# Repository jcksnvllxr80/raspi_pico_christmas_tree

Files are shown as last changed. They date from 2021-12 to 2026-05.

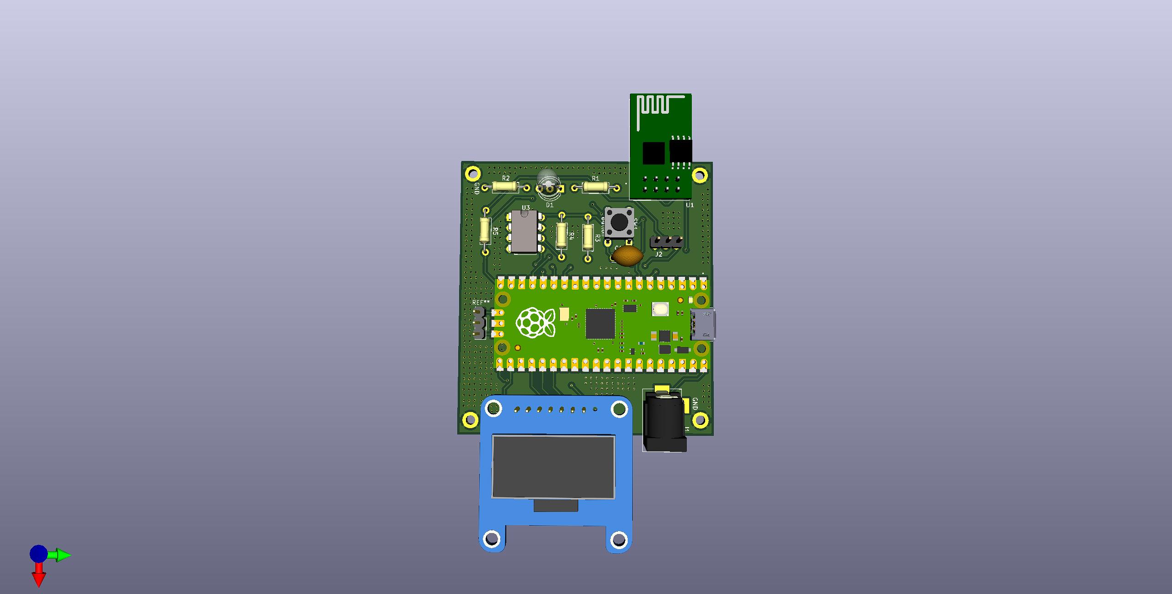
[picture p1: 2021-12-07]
pcb/images/raspi_pico_christmas_tree_front_3d.jpg

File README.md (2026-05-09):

# Raspberry Pi Pico with ws2812 LED string, SSD1306 OLED display, esp8266 (esp-01), and 24LC512 EEPROM. "Christmas Lights"







## Image of project // still a WIP

<p align="center">

</p>

<p align="center">

</p>

## Description

This project was designed for a decorative Christmas tree made out of cedar which stands about two feet in height. It consists of a Raspberry Pi Pico, a string of ws2812 neopixels, a 128x64 pixel (model: SSD1306) OLED display, an EEPROM (model: 24LC512), a standard push-button, and a esp8266 esp-01 module. The string of lights serve as the lights on the wooden Christmas tree and are controlled by one wire sending data in series to the lights. each new received value pushes the previous down the line to the next light. The different patterns of the lights are cycled through by pressing the push-button. The OLED display communication protocol is SPI and this display is used to give feedback to the user in form of the name of the LED string lighting style name. The time will be displayed after no button activity has occurred in a certain number of seconds (TBD). The time is obtained by using the esp8266 module to connect to the internet through the LAN wifi and obtain the time from a time server. Each time the led string lighting style changes, the array index of that style is stored in the EEPROM so that on next start up that setting is immediately recalled and used. I2C protocol is used to talk to the EEPROM. There is also a standalone LED that indicates whether wifi is connected or not (red/green common cathode LED).

## Prerequisites

The following classes (which are all in this repo) must be manually loaded onto the pico for this project to work:

- base64.py
- EEPROM_24LC512.py
- esp8266.py
- httpParser.py
- image_utils.py
- neopixel.py
- ssd1306.py
- main.py

## Installing / Updating

The `tools/` directory contains one-shot installer scripts for Windows (`install.bat`) and macOS (`install.sh`) that handle everything from a completely bare machine — no git, Python, or anything else required. They install all dependencies, clone the repo, flash the correct set of files to the Pico via `mpremote`, and uninstall everything they added when done.

```
# Windows
tools\install.bat              # LEDs only (no wifi/clock)
tools\install.bat --wifi       # full firmware with wifi + NTP clock
tools\install.bat --pineapple  # pineapple LED layout

# macOS
tools/install.sh               # LEDs only (no wifi/clock)
tools/install.sh --wifi        # full firmware with wifi + NTP clock
tools/install.sh --pineapple   # pineapple LED layout
```

See [`tools/README.md`](tools/README.md) for full details on what each flag does, which files get uploaded, and how the wifi credential flow works.

## Flashing MicroPython firmware (brand new Pico)

Skip this section if the Pico already responds as a serial/COM port — it already has MicroPython.

1. Download the latest MicroPython `.uf2` for the RP2040 from **https://micropython.org/download/RPI_PICO/**
2. Hold the **BOOTSEL** button on the Pico, plug it into USB, then release the button.
3. It mounts as a drive called **RPI-RP2** — drag and drop the `.uf2` file onto that drive.
4. The Pico reboots automatically and is now running MicroPython. It will show up as a serial/COM port instead of a drive.

Once you see the COM port you're ready to use `mpremote` or run the installer scripts in `tools/`.

## Upload a single file to the Pico

The Pico must already be running MicroPython (shows up as a COM port, not as the BOOTSEL drive).

```sh
pip install --user mpremote
python -m mpremote cp main.py :main.py + reset
```

Swap `main.py` for whichever file you want to overwrite. The `+ reset` soft-resets the controller immediately after the copy so the new code takes effect. `python -m mpremote ls` lists what's on the device.

To delete a file:

```sh
python -m mpremote rm :neopixel.py
```

To dump the contents of a file to the terminal:

```sh
python -m mpremote exec "print(open('main.py').read())"
```

## Text Image Creation

  1. open paint and set the properties canvas size to the number of pixels on the display (128,64)
  2. add some text with cool font and different size as well as bold and get it centered in the canvas
  3. select all (ctrl+a) then right click the image and invert colors
  4. save the image to a place easy to get to
  5. got to <https://javl.github.io/image2cpp/> and open the image from the previous step
  6. convert it and then use the *_img files in this proj as a template on how to use that data

## TODO

- use various waveforms to mask the brightness of the strip... i.e. cos, tan, sawtooth, triangle
- similarly to above, mask the waveforms along the time domain

### USE THONNY TO WRITE THE FOLLOWING CODE TO PI PICO WHICH IS CONTROLLING ESP8266-01

```python
from machine import UART, Pin
user_agent="RPi-Pico"
host="worldtimeapi.org"
path="/api/timezone/America/New_York"
getHeader = "GET "+path+" HTTP/1.1\r\n"+"Host: " + host+"\r\n"+"User-Agent: "+user_agent+"\r\n"+"\r\n"
txData = "AT+CIPSEND="+str(len(getHeader))+"\r\n"
UART_Tx_BUFFER_LENGTH = 1024
UART_Rx_BUFFER_LENGTH = 1024*2
UART_BAUD = 115_200
uart_port = 1
uart_tx_pin = 4
uart_rx_pin = 5
esp = UART(uart_port, baudrate=UART_BAUD, tx=Pin(uart_tx_pin), rx=Pin(uart_rx_pin), txbuf=UART_Tx_BUFFER_LENGTH, rxbuf=UART_Rx_BUFFER_LENGTH)
esp.write('AT\r\n'); esp.read()
esp.write('AT+GMR\r\n'); esp.read()
esp.write('ATE1\r\n'); esp.read()
esp.write('AT+GMR\r\n'); esp.read()
esp.write('AT+CWMODE_CUR=3\r\n'); esp.read()
esp.write('AT+CWJAP_CUR="<YOUR_SSID>","<YOUR_PASSWORD>"\r\n'); esp.read()
esp.write('AT+CIPSTATUS\r\n'); esp.read()
esp.write('AT+CIPSTART="TCP","worldtimeapi.org",80\r\n'); esp.read()
esp.write('AT+CWLIF\r\n'); esp.read()
esp.write('AT+HTTPCLIENT=1,0,"http://httpbin.org/get","httpbin.org","/get",1\r\n'); esp.read()
esp.write('AT+CIPSTART="TCP","worldtimeapi.org",80\r\n'); esp.read()
esp.write("AT+CIPSEND="+str(len(getHeader))+"\r\n"); esp.read()
esp.write(getHeader); esp.read()
esp.write("AT+PING=\"google.com\"\r\n"); esp.read()
esp.write("AT+PING=\"8.8.8.8\"\r\n"); esp.read()
esp.write("AT+CWJAP?\r\n"); esp.read(); esp.read()
esp.write("AT+CWQAP\r\n"); esp.read(); esp.read()
```

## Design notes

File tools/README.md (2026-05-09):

# Pico Christmas Tree — Installer Scripts

One-shot scripts to flash the correct branch of firmware onto the Pico from a machine that may have nothing pre-installed. Both scripts handle every dependency, upload all necessary files, and clean up after themselves when finished.

---

## Scripts

| Script | Platform |
|---|---|
| `install.bat` | Windows |
| `install.sh` | macOS |

---

## Requirements (hardware)

- Raspberry Pi Pico connected via a **data-capable** USB cable (not a charge-only cable)
- Internet connection (for cloning the repo and downloading dependencies)

---

## Usage

### Windows

```cmd
install.bat              # default: remove_wifi_and_clock branch
install.bat -w           # master branch (wifi + clock)
install.bat --wifi       # same as -w
install.bat -p           # led-pineapple branch
install.bat --pineapple  # same as -p
```

### macOS

Make the script executable once, then run it:

```bash
chmod +x install.sh
./install.sh              # default: remove_wifi_and_clock branch
./install.sh -w           # master branch (wifi + clock)
./install.sh --wifi       # same as -w
./install.sh -p           # led-pineapple branch
./install.sh --pineapple  # same as -p
```

---

## Branch / flag reference

| Flag | Branch | Description |
|---|---|---|
| *(none)* | `remove_wifi_and_clock` | LED effects only — no wifi, no clock |
| `-w` / `--wifi` | `master` | Full firmware: LED effects, OLED display, wifi, NTP time sync |
| `-p` / `--pineapple` | `led-pineapple` | LED effects configured for pineapple shape |

---

## What the scripts do

### Step 1 — Dependency checks and installs

The scripts check for each dependency and install it only if it is missing. Nothing is installed that is already present.

| Dependency | Windows — primary | Windows — fallback | macOS |
|---|---|---|---|
| Git | `winget` | Direct download via PowerShell (GitHub releases API) | Homebrew |
| Python 3.11 | `winget` | Direct download via PowerShell (python.org) | Homebrew |
| mpremote + pyserial | `pip` | `pip` | `pip` |
| Homebrew | — | — | Official install script |

**Windows installer fallback**

`winget` (App Installer) ships with all Windows 11 builds and Windows 10 version 1809+, but it can be missing on older Win10 machines, LTSC/enterprise images, or fresh VM installs. The script handles this gracefully:

1. Checks whether `winget` is available.
2. If yes, uses `winget install` as normal.
3. If no (or if `winget` reports success but the install fails), falls back to downloading the installer directly with PowerShell's `Invoke-WebRequest`:
   - **Git:** queries the [git-for-windows GitHub releases API](https://api.github.com/repos/git-for-windows/git/releases/latest) to get the latest 64-bit `.exe`, downloads it, and runs it silently.
   - **Python:** downloads the pinned `python-3.11.9-amd64.exe` directly from `python.org/ftp` and runs it silently with `PrependPath=1` (per-user install, no elevation required).

Both installers are deleted from the temp directory immediately after running.

> **Note (macOS):** After a fresh Homebrew install the script updates the shell's `PATH` automatically so subsequent steps work in the same session.

### Step 2 — Clone the repo

The target branch is cloned at depth 1 into a temporary directory. Nothing is written to your current working directory.

### Step 3 — WiFi credentials (`-w` / `--wifi` only)

A GUI popup asks for your WiFi SSID and password:

- **Windows:** two sequential Tkinter dialogs (password field is masked)
- **macOS:** two sequential system dialogs via `osascript` (password field is hidden)

The SSID and password are **base64-encoded** and injected into the config template (`conf/example_config.json`) to produce `conf/config.json`. This file is uploaded to the Pico and then immediately deleted from the local clone. It is also listed in `.gitignore` so it can never be accidentally committed.

### Step 4 — File upload via mpremote

Files are copied from the local clone to the root of the Pico's filesystem using `mpremote cp`. The `conf/` directory is the only subdirectory maintained on the Pico (master branch only).

#### Files uploaded per branch

| File (local path) | Pico destination | master | remove\_wifi | pineapple |
|---|---|---|---|---|
| `main.py` | `/main.py` | ✓ | ✓ | ✓ |
| `img/img_utils.py` | `/img_utils.py` | ✓ | ✓ | ✓ |
| `display/ssd1306.py` | `/ssd1306.py` | ✓ | ✓ | ✓ |
| `eeprom/EEPROM_24LC512.py` | `/EEPROM_24LC512.py` | ✓ | ✓ | ✓ |
| `neopixel/neopixel.py` | `/neopixel.py` | ✓ | ✓ | ✓ |
| `base64/base64.py` | `/base64.py` | ✓ | — | — |
| `http/httpParser.py` | `/httpParser.py` | ✓ | — | — |
| `wifi/esp8266.py` | `/esp8266.py` | ✓ | — | — |
| `conf/config.json` *(generated)* | `/conf/config.json` | ✓ | — | — |

> `img_utils.py` is a large pre-compiled file containing all LED effect image data as embedded bytearrays. The source PNG files under `img/numbers/` and `img/words/` are not uploaded.

> `eeprom/main.py` is a standalone test file and is intentionally excluded to avoid overwriting `/main.py` on the Pico.

### Step 5 — Cleanup

After the upload completes (or if an error occurs), everything the script installed is removed in reverse order:

1. Local repo clone (temp directory) — always removed
2. `mpremote` and `pyserial` — `pip uninstall`
3. Python — `winget uninstall` / `brew uninstall`
4. Git — `winget uninstall` / `brew uninstall`
5. Homebrew — official uninstall script (macOS only, if Homebrew was not present before)

Only items that were **installed by the script** are removed. If Python or Git was already on the machine before running the script, it will not be touched.

> **macOS:** cleanup is registered with `trap EXIT` so it runs even if the script fails partway through — no stranded installs.

> **Windows:** all error paths route through a shared cleanup block for the same guarantee.

---

## Troubleshooting

**Upload fails immediately**
The most common cause is a charge-only USB cable. Swap to a data cable and re-run.

**mpremote can't find the Pico**
If you have multiple serial devices connected, mpremote may pick the wrong one. Identify the correct port (`/dev/cu.usbmodemXXXX` on Mac, `COMX` on Windows) and prefix each `mpremote` call with `connect <port>`. The scripts currently rely on auto-detection.

**Windows: "Git/Python was installed but is not yet on PATH"**
This can happen if the installer updated the system PATH but the current cmd session hasn't picked it up. Close the terminal, open a new one, and re-run `install.bat`.

**Windows: winget fails and the PowerShell download also fails**
This usually means no internet access, or a corporate firewall is blocking `api.github.com` or `python.org`. Install [Git](https://git-scm.com) and [Python 3.11](https://python.org) manually, then re-run the script — it will detect them and skip straight to the upload.

**macOS: Homebrew install requires sudo / Xcode CLT prompt**
The Homebrew installer may pause to install Xcode Command Line Tools if they are missing. Follow the on-screen prompt and let it complete — the script will continue once Homebrew is ready.

**WiFi dialog doesn't appear (Windows)**
Tkinter is bundled with the official Python installer from python.org and the winget Python package. If it is missing, install Python manually with the standard installer and ensure the "tcl/tk and IDLE" option is checked.

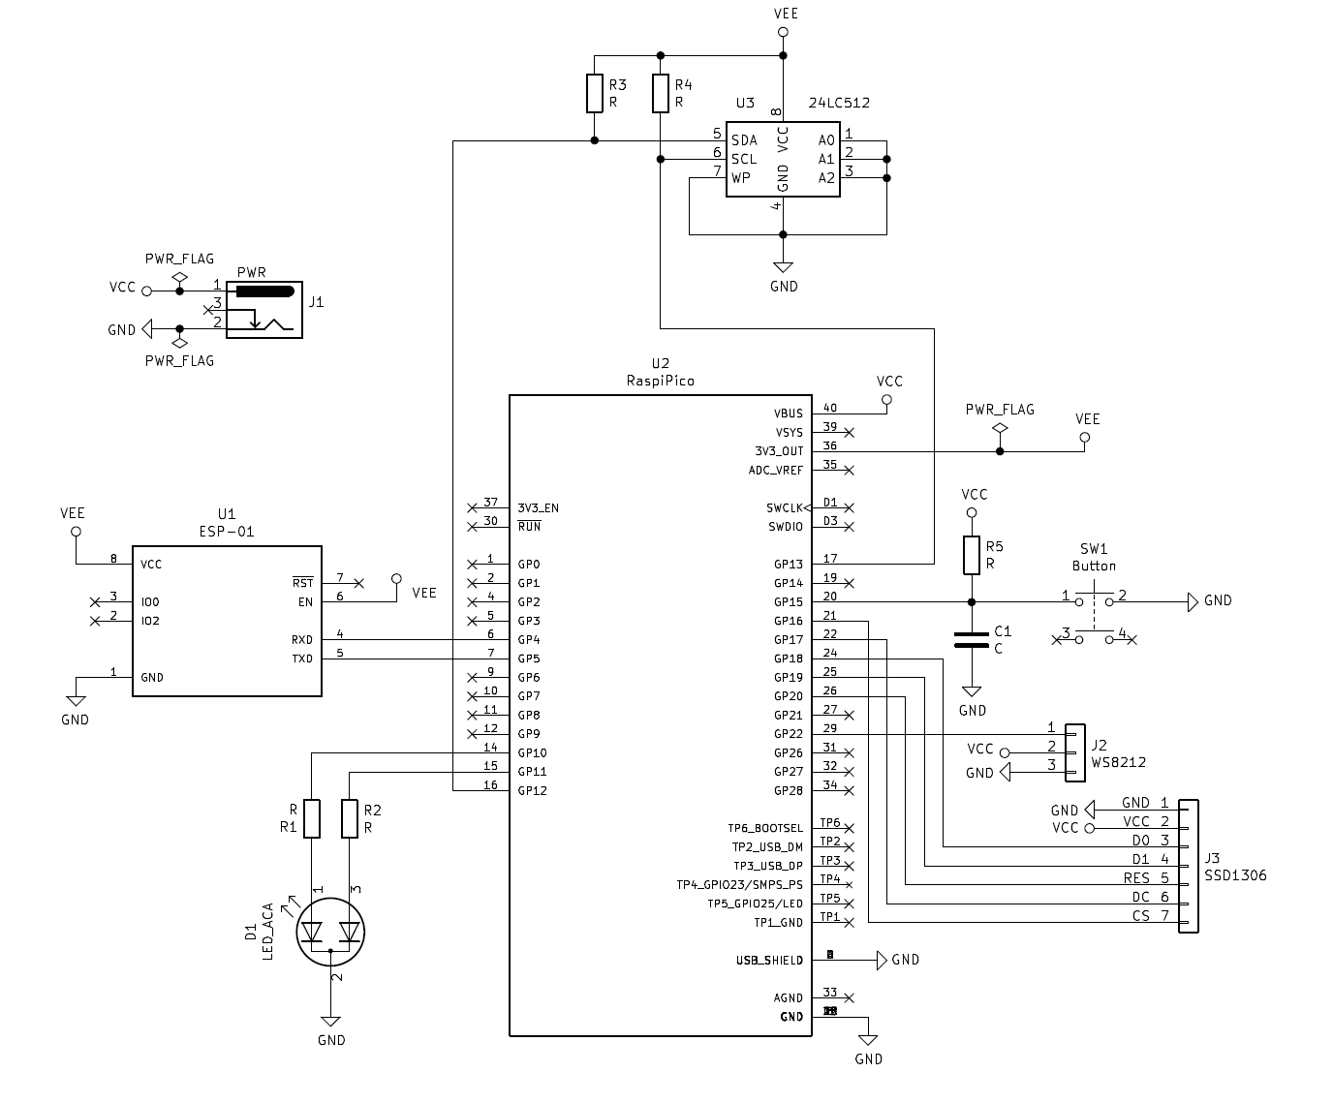
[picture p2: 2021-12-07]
pcb/images/schematic.png

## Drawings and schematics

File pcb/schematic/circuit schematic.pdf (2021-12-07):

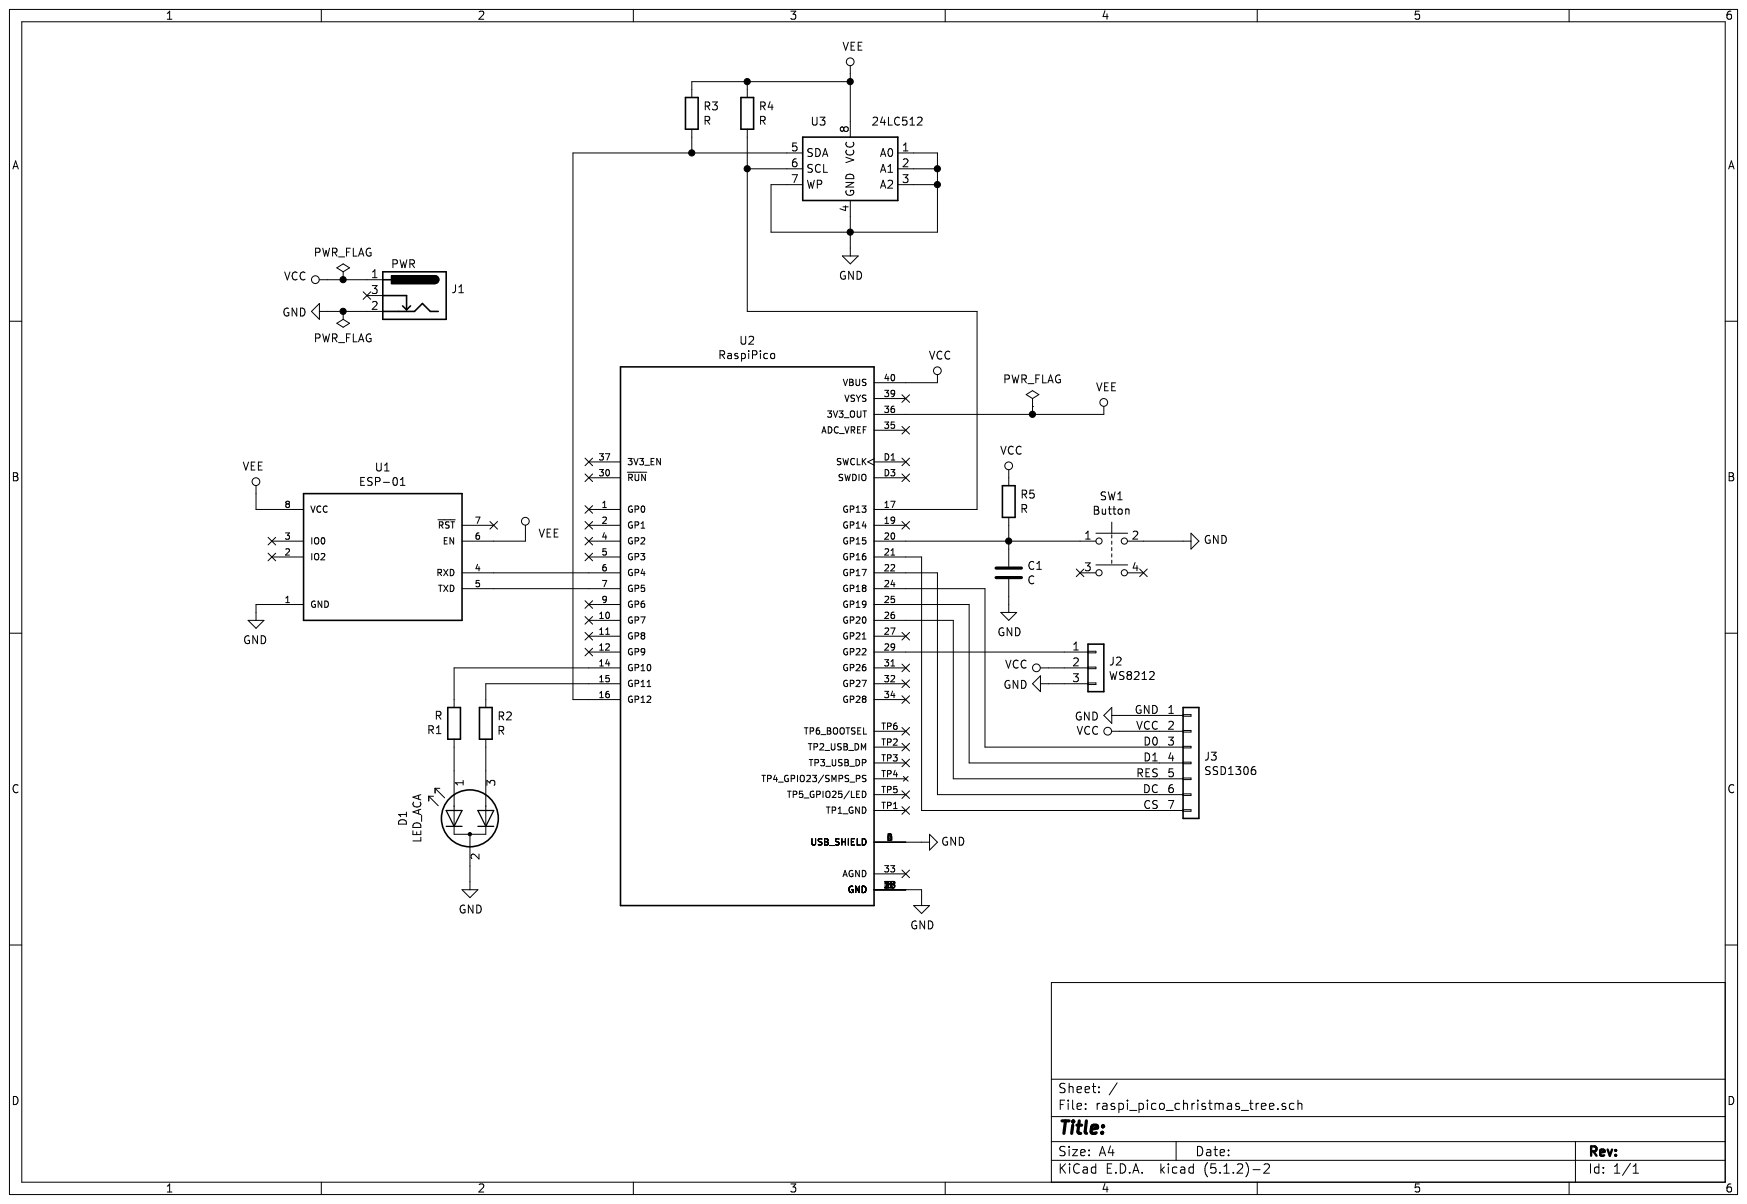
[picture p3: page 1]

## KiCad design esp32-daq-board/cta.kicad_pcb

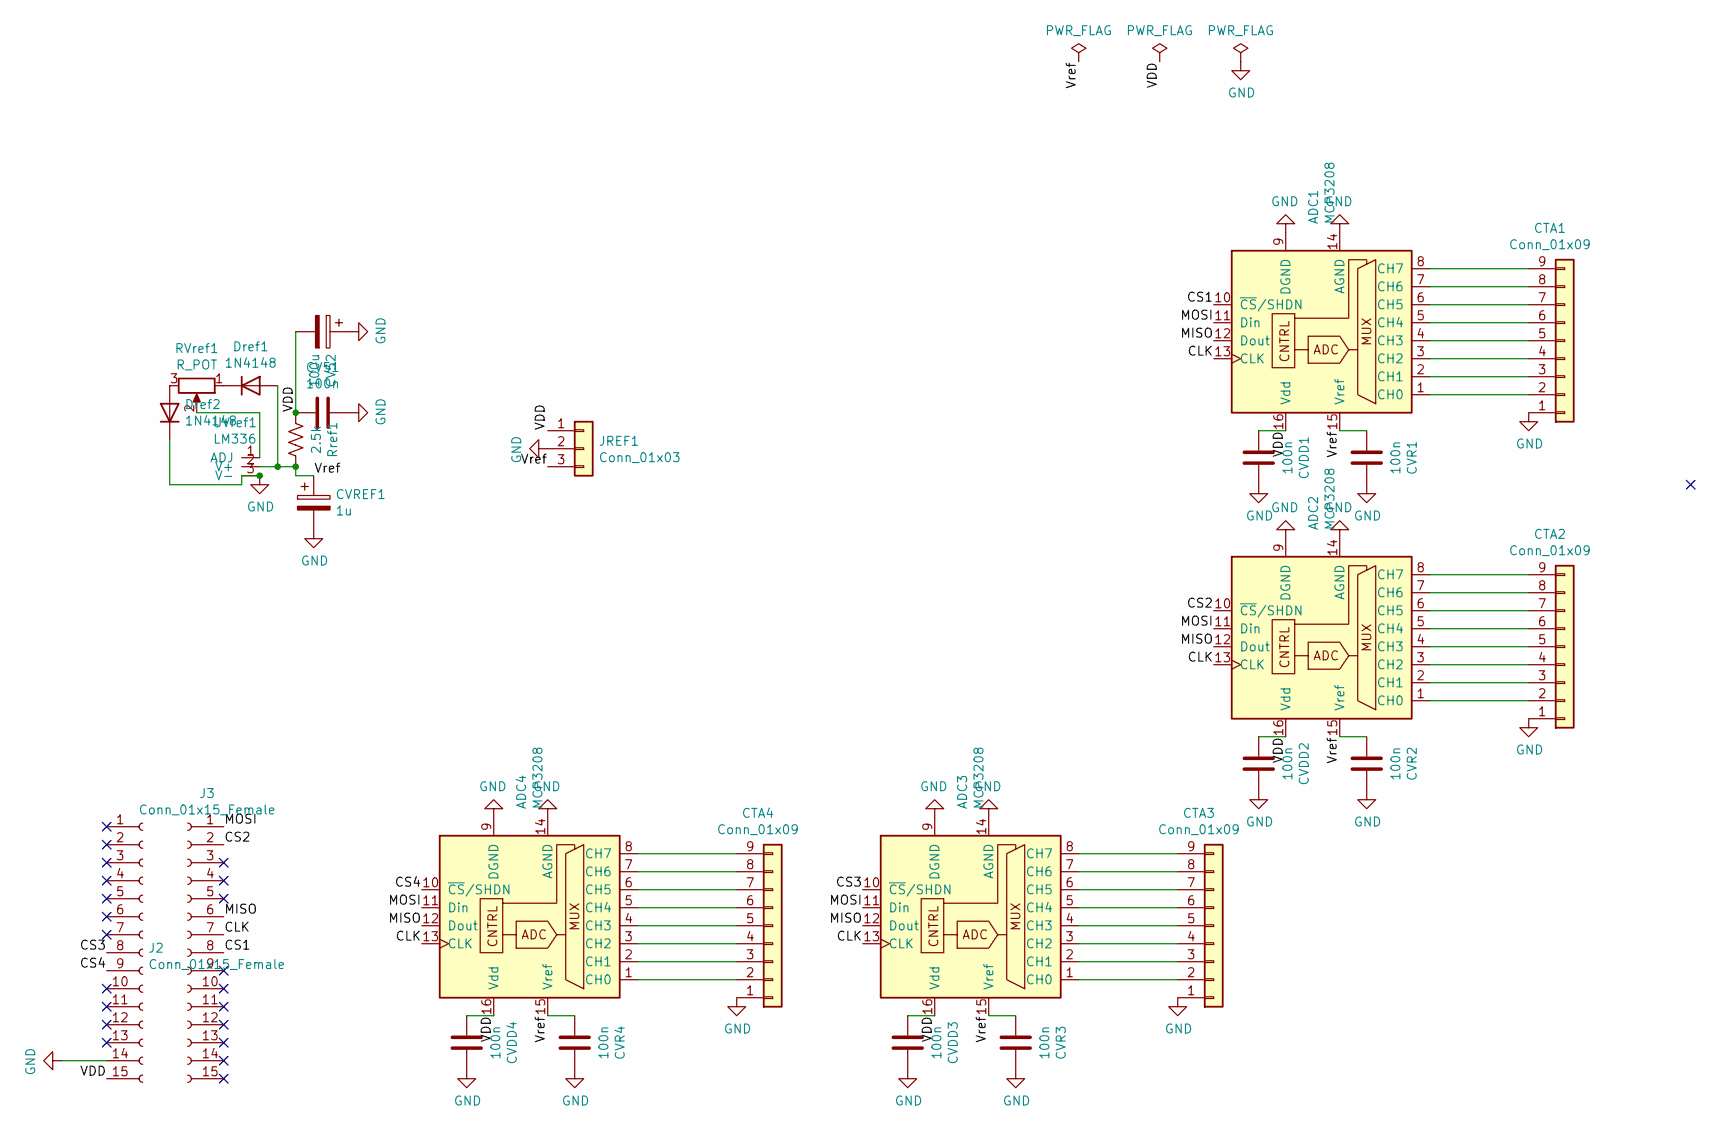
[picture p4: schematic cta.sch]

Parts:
ADC1, ADC2, ADC3, ADC4: MCP3208; DIP-16_W7.62mm_LongPads
CTA1, CTA2, CTA3, CTA4: Conn_01x09; PinHeader_1x09_P2.54mm_Vertical
CV51: 100n; C_Rect_L7.2mm_W3.0mm_P5.00mm_FKS2_FKP2_MKS2_MKP2
CV52: 100u; CP_Radial_D6.3mm_P2.50mm
CVDD1, CVDD2, CVDD3, CVDD4: 100n; C_Rect_L7.2mm_W3.0mm_P5.00mm_FKS2_FKP2_MKS2_MKP2
CVR1, CVR2, CVR3, CVR4: 100n; C_Rect_L7.2mm_W3.0mm_P5.00mm_FKS2_FKP2_MKS2_MKP2
CVREF1: 1u; CP_Radial_D4.0mm_P2.00mm
Dref1, Dref2: 1N4148; D_DO-35_SOD27_P7.62mm_Horizontal
J2, J3: Conn_01x15_Female; PinSocket_1x15_P2.54mm_Vertical
JREF1: Conn_01x03; TerminalBlock_bornier-3_P5.08mm
RVref1: R_POT; Potentiometer_Bourns_3296W_Vertical
Rref1: 2.5k; R_Axial_DIN0207_L6.3mm_D2.5mm_P10.16mm_Horizontal
UVref1: LM336; TO-92L_Inline_Wide

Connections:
/CLK: ADC1.13 (CLK), ADC2.13 (CLK), ADC3.13 (CLK), ADC4.13 (CLK), J3.7
/CS1: ADC1.10 (~CS~/SHDN), J3.8
/CS2: ADC2.10 (~CS~/SHDN), J3.2
/CS3: ADC3.10 (~CS~/SHDN), J2.8
/CS4: ADC4.10 (~CS~/SHDN), J2.9
/MISO: ADC1.12 (Dout), ADC2.12 (Dout), ADC3.12 (Dout), ADC4.12 (Dout), J3.6
/MOSI: ADC1.11 (Din), ADC2.11 (Din), ADC3.11 (Din), ADC4.11 (Din), J3.1
/VDD: ADC1.16 (Vdd), ADC2.16 (Vdd), ADC3.16 (Vdd), ADC4.16 (Vdd), CV51.2, CV52.2, CVDD1.2, CVDD2.2, CVDD3.2, CVDD4.2, J2.15, JREF1.1, Rref1.2
/Vref: ADC1.15 (Vref), ADC2.15 (Vref), ADC3.15 (Vref), ADC4.15 (Vref), CVR1.2, CVR2.2, CVR3.2, CVR4.2, CVREF1.1, Dref1.2 (A), JREF1.3, Rref1.1, UVref1.2 (V+)
GND: ADC1.9 (DGND), ADC1.14 (AGND), ADC2.9 (DGND), ADC2.14 (AGND), ADC3.9 (DGND), ADC3.14 (AGND), ADC4.9 (DGND), ADC4.14 (AGND), CTA1.1, CTA2.1, CTA3.1, CTA4.1, CV51.1, CV52.1, CVDD1.1, CVDD2.1, CVDD3.1, CVDD4.1, CVR1.1, CVR2.1, CVR3.1, CVR4.1, CVREF1.2, Dref2.1 (K), J2.14, JREF1.2, UVref1.3 (V-)
unnamed: ADC1.1 (CH0), CTA1.2
unnamed: ADC1.2 (CH1), CTA1.3
unnamed: ADC1.3 (CH2), CTA1.4
unnamed: ADC1.4 (CH3), CTA1.5
unnamed: ADC1.5 (CH4), CTA1.6
unnamed: ADC1.6 (CH5), CTA1.7
unnamed: ADC1.7 (CH6), CTA1.8
unnamed: ADC1.8 (CH7), CTA1.9
unnamed: ADC2.1 (CH0), CTA2.2
unnamed: ADC2.2 (CH1), CTA2.3
unnamed: ADC2.3 (CH2), CTA2.4
unnamed: ADC2.4 (CH3), CTA2.5
unnamed: ADC2.5 (CH4), CTA2.6
unnamed: ADC2.6 (CH5), CTA2.7
unnamed: ADC2.7 (CH6), CTA2.8
unnamed: ADC2.8 (CH7), CTA2.9
unnamed: ADC3.1 (CH0), CTA3.2
unnamed: ADC3.2 (CH1), CTA3.3
unnamed: ADC3.3 (CH2), CTA3.4
unnamed: ADC3.4 (CH3), CTA3.5
unnamed: ADC3.5 (CH4), CTA3.6
unnamed: ADC3.6 (CH5), CTA3.7
unnamed: ADC3.7 (CH6), CTA3.8
unnamed: ADC3.8 (CH7), CTA3.9
unnamed: ADC4.1 (CH0), CTA4.2
unnamed: ADC4.2 (CH1), CTA4.3
unnamed: ADC4.3 (CH2), CTA4.4
unnamed: ADC4.4 (CH3), CTA4.5
unnamed: ADC4.5 (CH4), CTA4.6
unnamed: ADC4.6 (CH5), CTA4.7
unnamed: ADC4.7 (CH6), CTA4.8
unnamed: ADC4.8 (CH7), CTA4.9
unnamed: Dref1.1 (K), RVref1.1
unnamed: Dref2.2 (A), RVref1.3
unnamed: RVref1.2, UVref1.1 (ADJ)

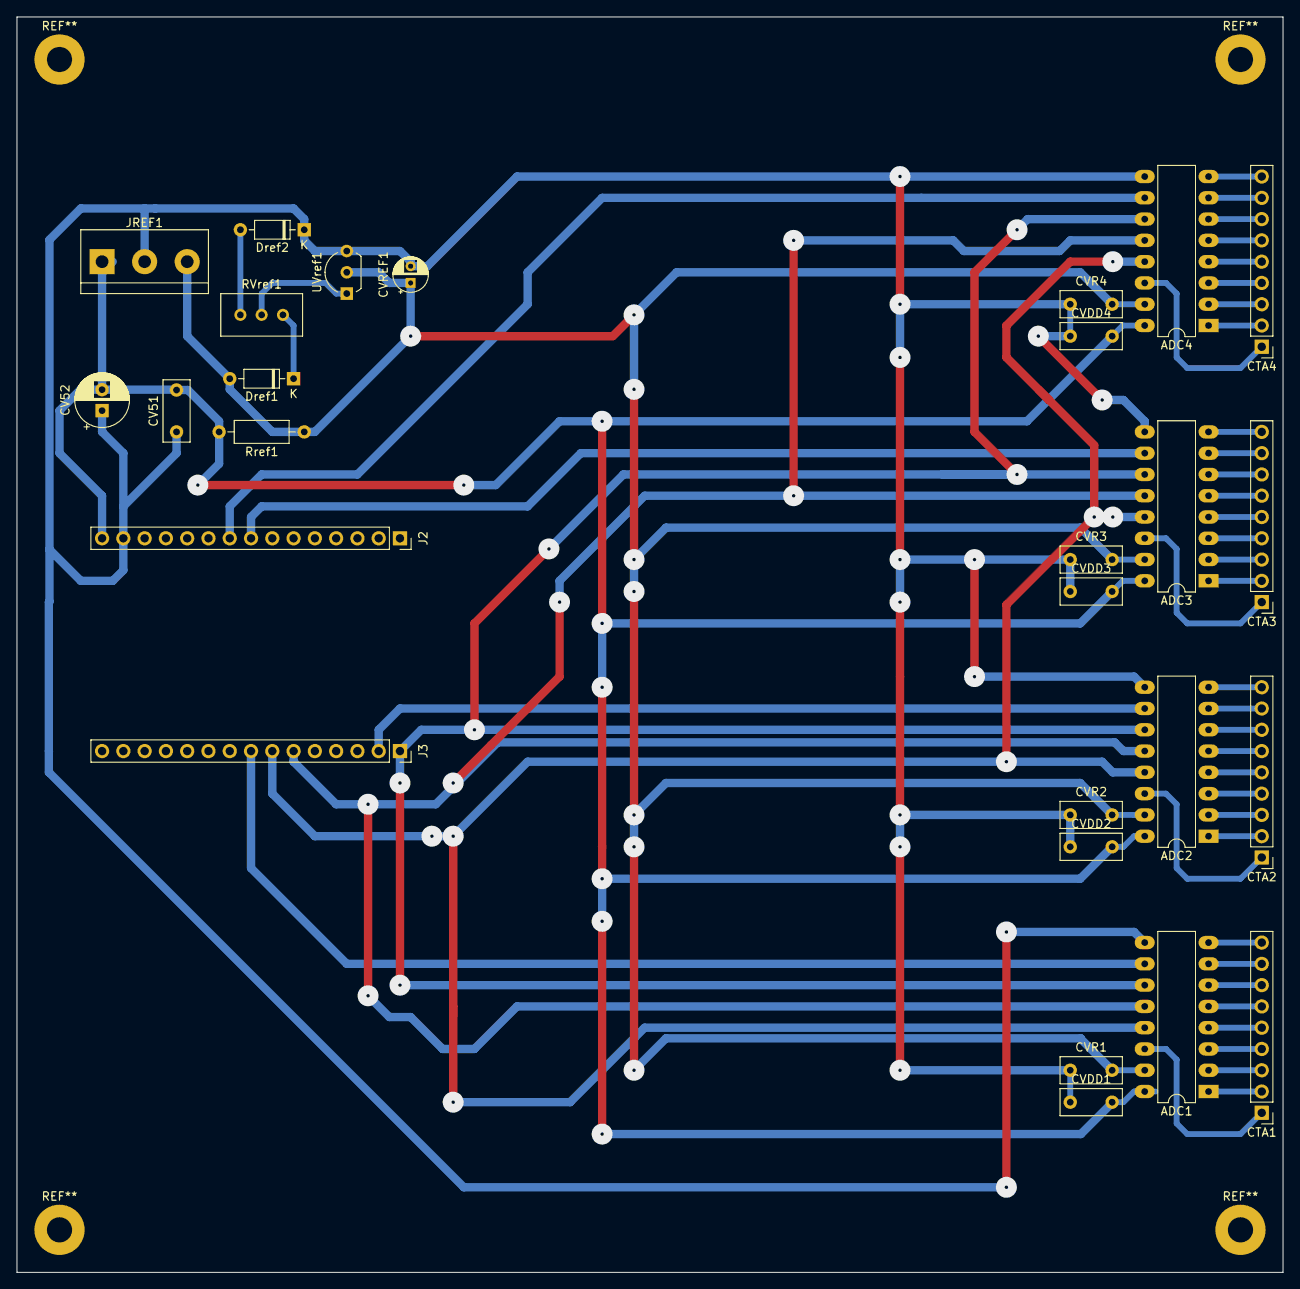
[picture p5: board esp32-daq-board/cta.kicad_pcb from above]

Board: 2 copper layers, 151.1 x 149.9 mm, 27 parts (0 on the bottom side), 45 nets.

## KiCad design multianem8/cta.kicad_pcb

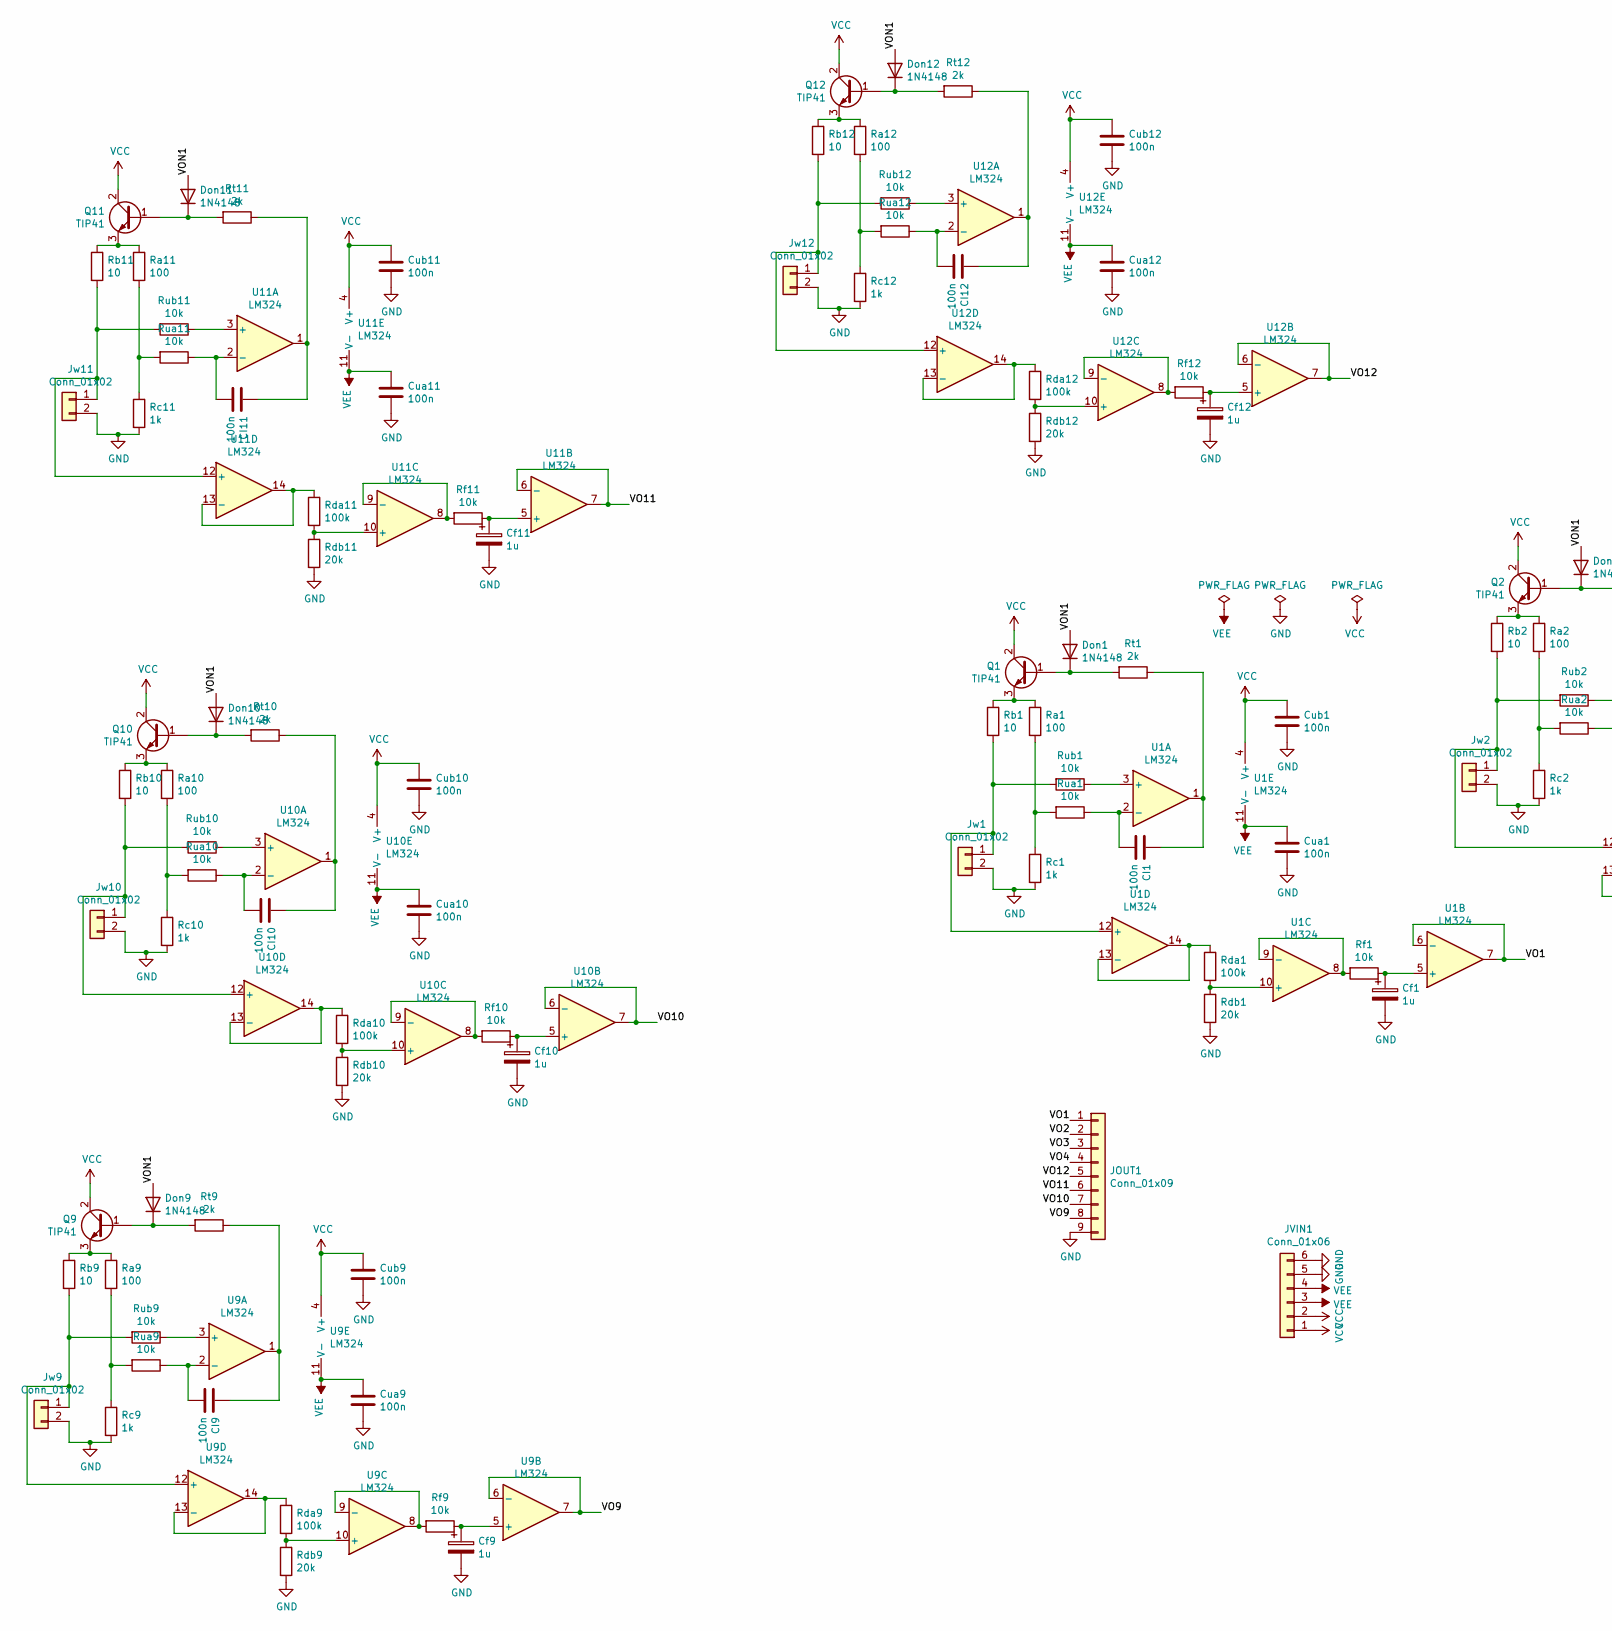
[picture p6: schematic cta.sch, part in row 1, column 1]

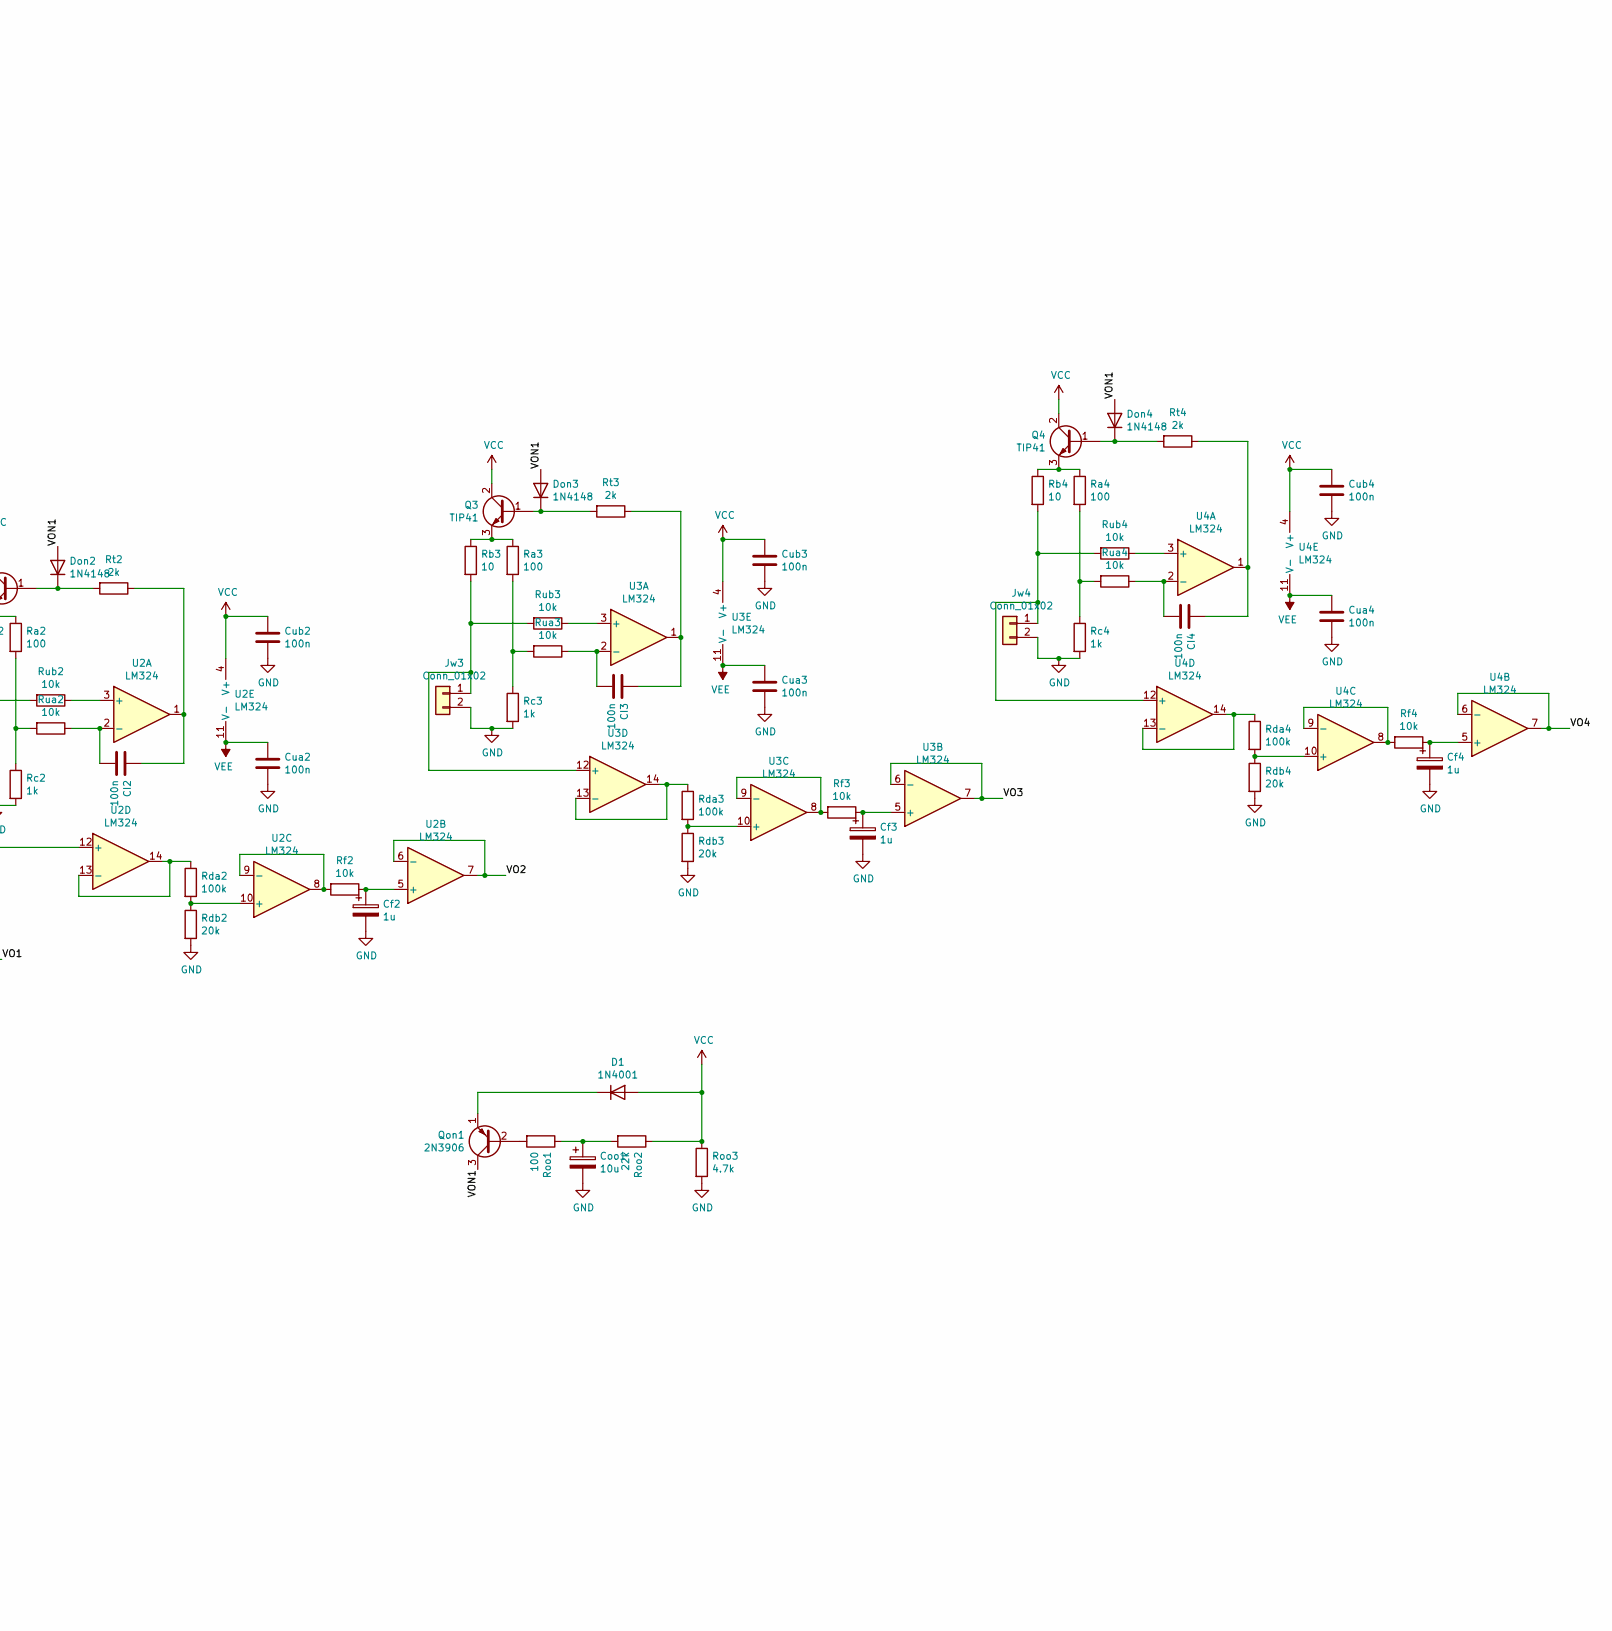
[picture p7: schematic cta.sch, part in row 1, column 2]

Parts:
CI1, CI2, CI3, CI4, CI9, CI10, CI11, CI12: 100n; C_Rect_L7.2mm_W3.5mm_P5.00mm_FKS2_FKP2_MKS2_MKP2
Cf1, Cf2, Cf3, Cf4, Cf9, Cf10, Cf11, Cf12: 1u; CP_Radial_D5.0mm_P2.50mm
Coo1: 10u; CP_Radial_D5.0mm_P2.50mm
Cua1, Cua2, Cua3, Cua4, Cua9, Cua10, Cua11, Cua12: 100n; C_Disc_D5.0mm_W2.5mm_P2.50mm
Cub1, Cub2, Cub3, Cub4, Cub9, Cub10, Cub11, Cub12: 100n; C_Disc_D5.0mm_W2.5mm_P2.50mm
D1: 1N4001; D_DO-41_SOD81_P10.16mm_Horizontal
Don1, Don2, Don3, Don4, Don9, Don10, Don11, Don12: 1N4148; D_DO-35_SOD27_P7.62mm_Horizontal
JOUT1: Conn_01x09; PinHeader_1x09_P2.54mm_Vertical
JVIN1: Conn_01x06; TerminalBlock_bornier-6_P5.08mm
Jw1, Jw2, Jw3, Jw4, Jw9, Jw10, Jw11, Jw12: Conn_01x02; PinHeader_1x02_P2.54mm_Vertical
Q1, Q2, Q3, Q4, Q9, Q10, Q11, Q12: TIP41; TO-220-3_Vertical
Qon1: 2N3906; TO-92_Inline_Wide
Ra1, Ra2, Ra3, Ra4, Ra9, Ra10, Ra11, Ra12: 100; R_Axial_DIN0207_L6.3mm_D2.5mm_P10.16mm_Horizontal
Rb1, Rb2, Rb3, Rb4, Rb9, Rb10, Rb11, Rb12: 10; R_Axial_DIN0414_L11.9mm_D4.5mm_P15.24mm_Horizontal
Rc1, Rc2, Rc3, Rc4, Rc9, Rc10, Rc11, Rc12: 1k; R_Axial_DIN0207_L6.3mm_D2.5mm_P10.16mm_Horizontal
Rda1, Rda2, Rda3, Rda4, Rda9, Rda10, Rda11, Rda12: 100k; R_Axial_DIN0207_L6.3mm_D2.5mm_P10.16mm_Horizontal
Rdb1, Rdb2, Rdb3, Rdb4, Rdb9, Rdb10, Rdb11, Rdb12: 20k; R_Axial_DIN0207_L6.3mm_D2.5mm_P10.16mm_Horizontal
Rf1, Rf2, Rf3, Rf4, Rf9, Rf10, Rf11, Rf12: 10k; R_Axial_DIN0207_L6.3mm_D2.5mm_P10.16mm_Horizontal
Roo1: 100; R_Axial_DIN0207_L6.3mm_D2.5mm_P10.16mm_Horizontal
Roo2: 22k; R_Axial_DIN0207_L6.3mm_D2.5mm_P10.16mm_Horizontal
Roo3: 4.7k; R_Axial_DIN0207_L6.3mm_D2.5mm_P10.16mm_Horizontal
Rt1, Rt2, Rt3, Rt4, Rt9, Rt10, Rt11, Rt12: 2k; R_Axial_DIN0207_L6.3mm_D2.5mm_P10.16mm_Horizontal
Rua1, Rua2, Rua3, Rua4, Rua9, Rua10, Rua11, Rua12: 10k; R_Axial_DIN0207_L6.3mm_D2.5mm_P10.16mm_Horizontal
Rub1, Rub2, Rub3, Rub4, Rub9, Rub10, Rub11, Rub12: 10k; R_Axial_DIN0207_L6.3mm_D2.5mm_P10.16mm_Horizontal
U1, U2, U3, U4, U9, U10, U11, U12: LM324; DIP-14_W7.62mm_LongPads

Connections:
/VO1: JOUT1.1, U1.6 (-), U1.7
/VO2: JOUT1.2, U2.6 (-), U2.7
/VO3: JOUT1.3, U3.6 (-), U3.7
/VO4: JOUT1.4, U4.6 (-), U4.7
/VO9: JOUT1.8, U9.6 (-), U9.7
/VO10: JOUT1.7, U10.6 (-), U10.7
/VO11: JOUT1.6, U11.6 (-), U11.7
/VO12: JOUT1.5, U12.6 (-), U12.7
/VON1: Don1.2 (A), Don2.2 (A), Don3.2 (A), Don4.2 (A), Don9.2 (A), Don10.2 (A), Don11.2 (A), Don12.2 (A), Qon1.3 (C)
GND: Cf1.2, Cf2.2, Cf3.2, Cf4.2, Cf9.2, Cf10.2, Cf11.2, Cf12.2, Coo1.2, Cua1.2, Cua2.2, Cua3.2, Cua4.2, Cua9.2, Cua10.2, Cua11.2, Cua12.2, Cub1.2, Cub2.2, Cub3.2, Cub4.2, Cub9.2, Cub10.2, Cub11.2, Cub12.2, JOUT1.9, JVIN1.5, JVIN1.6, Jw1.2, Jw2.2, Jw3.2, Jw4.2, Jw9.2, Jw10.2, Jw11.2, Jw12.2, Rc1.2, Rc2.2, Rc3.2, Rc4.2, Rc9.2, Rc10.2, Rc11.2, Rc12.2, Rdb1.2, Rdb2.2, Rdb3.2, Rdb4.2, Rdb9.2, Rdb10.2, Rdb11.2, Rdb12.2, Roo3.2
unnamed: CI1.1, Rt1.1, U1.1
unnamed: CI1.2, Rua1.1, U1.2 (-)
unnamed: CI2.1, Rt2.1, U2.1
unnamed: CI2.2, Rua2.1, U2.2 (-)
unnamed: CI3.1, Rt3.1, U3.1
unnamed: CI3.2, Rua3.1, U3.2 (-)
unnamed: CI4.1, Rt4.1, U4.1
unnamed: CI4.2, Rua4.1, U4.2 (-)
unnamed: CI9.1, Rt9.1, U9.1
unnamed: CI9.2, Rua9.1, U9.2 (-)
unnamed: CI10.1, Rt10.1, U10.1
unnamed: CI10.2, Rua10.1, U10.2 (-)
unnamed: CI11.1, Rt11.1, U11.1
unnamed: CI11.2, Rua11.1, U11.2 (-)
unnamed: CI12.1, Rt12.1, U12.1
unnamed: CI12.2, Rua12.1, U12.2 (-)
unnamed: Cf1.1, Rf1.1, U1.5 (+)
unnamed: Cf2.1, Rf2.1, U2.5 (+)
unnamed: Cf3.1, Rf3.1, U3.5 (+)
unnamed: Cf4.1, Rf4.1, U4.5 (+)
unnamed: Cf9.1, Rf9.1, U9.5 (+)
unnamed: Cf10.1, Rf10.1, U10.5 (+)
unnamed: Cf11.1, Rf11.1, U11.5 (+)
unnamed: Cf12.1, Rf12.1, U12.5 (+)
unnamed: Coo1.1, Roo1.1, Roo2.2
unnamed: D1.1 (K), Qon1.1 (E)
unnamed: Don1.1 (K), Q1.1 (B), Rt1.2
unnamed: Don2.1 (K), Q2.1 (B), Rt2.2
unnamed: Don3.1 (K), Q3.1 (B), Rt3.2
unnamed: Don4.1 (K), Q4.1 (B), Rt4.2
unnamed: Don9.1 (K), Q9.1 (B), Rt9.2
unnamed: Don10.1 (K), Q10.1 (B), Rt10.2
unnamed: Don11.1 (K), Q11.1 (B), Rt11.2
unnamed: Don12.1 (K), Q12.1 (B), Rt12.2
unnamed: Jw1.1, Rb1.2, Rub1.2, U1.12 (+)
unnamed: Jw2.1, Rb2.2, Rub2.2, U2.12 (+)
unnamed: Jw3.1, Rb3.2, Rub3.2, U3.12 (+)
unnamed: Jw4.1, Rb4.2, Rub4.2, U4.12 (+)
unnamed: Jw9.1, Rb9.2, Rub9.2, U9.12 (+)
unnamed: Jw10.1, Rb10.2, Rub10.2, U10.12 (+)
unnamed: Jw11.1, Rb11.2, Rub11.2, U11.12 (+)
unnamed: Jw12.1, Rb12.2, Rub12.2, U12.12 (+)
unnamed: Q1.3 (E), Ra1.1, Rb1.1
unnamed: Q2.3 (E), Ra2.1, Rb2.1
unnamed: Q3.3 (E), Ra3.1, Rb3.1
unnamed: Q4.3 (E), Ra4.1, Rb4.1
unnamed: Q9.3 (E), Ra9.1, Rb9.1
unnamed: Q10.3 (E), Ra10.1, Rb10.1
unnamed: Q11.3 (E), Ra11.1, Rb11.1
unnamed: Q12.3 (E), Ra12.1, Rb12.1
unnamed: Qon1.2 (B), Roo1.2
unnamed: Ra1.2, Rc1.1, Rua1.2
unnamed: Ra2.2, Rc2.1, Rua2.2
unnamed: Ra3.2, Rc3.1, Rua3.2
unnamed: Ra4.2, Rc4.1, Rua4.2
unnamed: Ra9.2, Rc9.1, Rua9.2
unnamed: Ra10.2, Rc10.1, Rua10.2
unnamed: Ra11.2, Rc11.1, Rua11.2
unnamed: Ra12.2, Rc12.1, Rua12.2
unnamed: Rda1.1, U1.13 (-), U1.14
unnamed: Rda1.2, Rdb1.1, U1.10 (+)
unnamed: Rda2.1, U2.13 (-), U2.14
unnamed: Rda2.2, Rdb2.1, U2.10 (+)
unnamed: Rda3.1, U3.13 (-), U3.14
unnamed: Rda3.2, Rdb3.1, U3.10 (+)
unnamed: Rda4.1, U4.13 (-), U4.14
unnamed: Rda4.2, Rdb4.1, U4.10 (+)
unnamed: Rda9.1, U9.13 (-), U9.14
unnamed: Rda9.2, Rdb9.1, U9.10 (+)
unnamed: Rda10.1, U10.13 (-), U10.14
unnamed: Rda10.2, Rdb10.1, U10.10 (+)
unnamed: Rda11.1, U11.13 (-), U11.14
unnamed: Rda11.2, Rdb11.1, U11.10 (+)
unnamed: Rda12.1, U12.13 (-), U12.14
unnamed: Rda12.2, Rdb12.1, U12.10 (+)
unnamed: Rf1.2, U1.8, U1.9 (-)
unnamed: Rf2.2, U2.8, U2.9 (-)
unnamed: Rf3.2, U3.8, U3.9 (-)
unnamed: Rf4.2, U4.8, U4.9 (-)
unnamed: Rf9.2, U9.8, U9.9 (-)
unnamed: Rf10.2, U10.8, U10.9 (-)
unnamed: Rf11.2, U11.8, U11.9 (-)
unnamed: Rf12.2, U12.8, U12.9 (-)
unnamed: Rub1.1, U1.3 (+)
unnamed: Rub2.1, U2.3 (+)
unnamed: Rub3.1, U3.3 (+)
unnamed: Rub4.1, U4.3 (+)
unnamed: Rub9.1, U9.3 (+)
unnamed: Rub10.1, U10.3 (+)
unnamed: Rub11.1, U11.3 (+)
unnamed: Rub12.1, U12.3 (+)
VCC: Cub1.1, Cub2.1, Cub3.1, Cub4.1, Cub9.1, Cub10.1, Cub11.1, Cub12.1, D1.2 (A), JVIN1.1, JVIN1.2, Q1.2 (C), Q2.2 (C), Q3.2 (C), Q4.2 (C), Q9.2 (C), Q10.2 (C), Q11.2 (C), Q12.2 (C), Roo2.1, Roo3.1, U1.4 (V+), U2.4 (V+), U3.4 (V+), U4.4 (V+), U9.4 (V+), U10.4 (V+), U11.4 (V+), U12.4 (V+)
VEE: Cua1.1, Cua2.1, Cua3.1, Cua4.1, Cua9.1, Cua10.1, Cua11.1, Cua12.1, JVIN1.3, JVIN1.4, U1.11 (V-), U2.11 (V-), U3.11 (V-), U4.11 (V-), U9.11 (V-), U10.11 (V-), U11.11 (V-), U12.11 (V-)

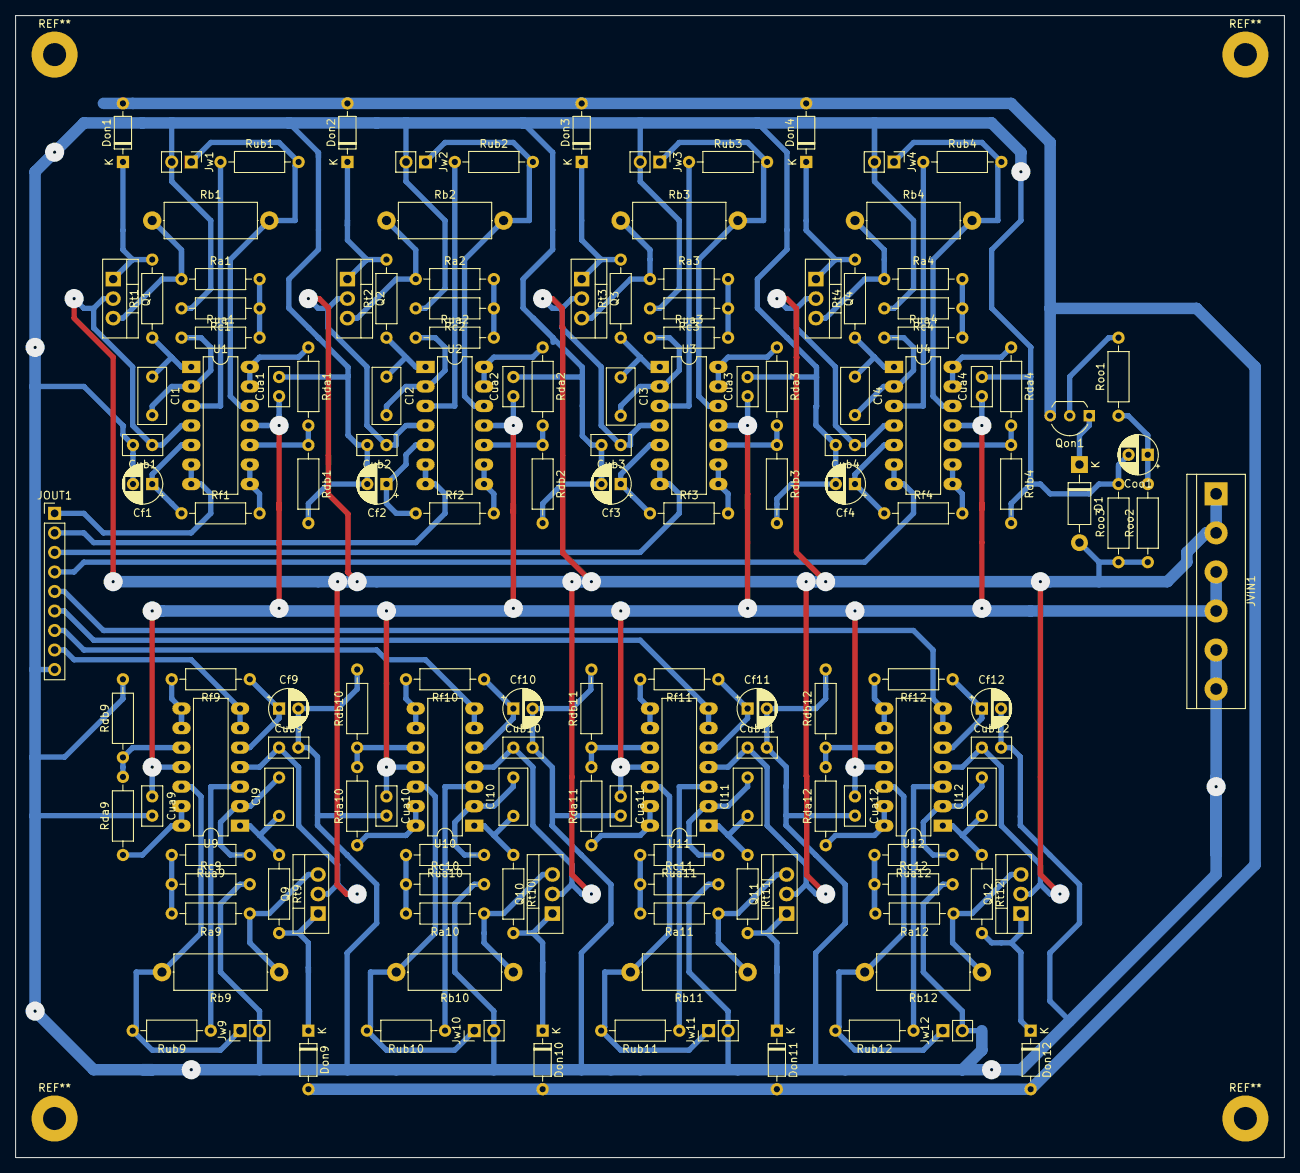
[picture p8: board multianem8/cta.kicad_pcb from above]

Board: 2 copper layers, 165.1 x 148.6 mm, 144 parts (0 on the bottom side), 103 nets.

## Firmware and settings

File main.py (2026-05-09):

# Example using PIO to drive a set of WS2812 LEDs.

import sys
from esp8266 import ESP8266, ESP8266_WIFI_CONNECTED
from machine import Pin, SPI, Timer, I2C, RTC
from EEPROM_24LC512 import EEPROM_24LC512
from ssd1306 import SSD1306_SPI
import framebuf
from utime import sleep_ms, time
import img_utils
from neopixel import Neopixel
import random
import base64
import ujson
from math import sin

# Perceptual brightness curve — RGB output is non-linear in perceived intensity,
# so dim ramps look "jumpy". Lookup table maps linear input to gamma 2.6 output.
GAMMA = bytes(int(((i / 255.0) ** 2.6) * 255 + 0.5) for i in range(256))

print("~~~~~~~~~~~~~~~~~~~~~~~~~~~~~~~~~~~~~~~~~~~~~")
print("RPi-Pico MicroPython Ver:", sys.version)
print("~~~~~~~~~~~~~~~~~~~~~~~~~~~~~~~~~~~~~~~~~~~~~")

CONFIG_FILE = "conf/config.json"
INACTIVITY_TIMER = 7
BLANK_TIMER = 30
PHASE_IMAGE = 0  # effect image shown; button advances effect
PHASE_TIME  = 1  # time shown; button wakes to image
PHASE_BLANK = 2  # display off; button wakes to image
STYLE_BYTES = 2
STYLE_ADDRESS = 0
I2C_FREQ = 1_000_000
SPI_FREQ = 4_000_000
SPI_PORT = 0
UART_BAUD = 115_200
COLON = ':'
WIFI_MODE = 3
WIFI_CHECK_PERIOD = 3_600_000  # milliseconds (hourly)
# HOURS_PER_DAY = 24
# HOURS_TO_SYNC_TIME = list(range(HOURS_PER_DAY))
# HOUR_POSITION = 4
uart_port = 1
uart_tx_pin = 4
uart_rx_pin = 5
# Configure the number/order of WS2812 LEDs.
ROW0 = [18, 19, 20, 21, 22, 23, 24, 25]
ROW1 = [15, 16, 17, 26, 27, 28]
ROW2 = [12, 13, 14, 29,30, 31]
ROW3 = [10, 11, 32, 33]
ROW4 = [1, 2, 8, 9]
ROW5 = [3, 7]
ROW6 = [4, 6]
ROW7 = [5]
ROWS_BTM_2_TOP = [ROW0, ROW1, ROW2, ROW3, ROW4, ROW5, ROW6, ROW7]
ROWS_TOP_2_BTM = ROWS_BTM_2_TOP[::-1]
NUM_ROWS = len(ROWS_BTM_2_TOP)
NUM_LEDS = sum(len(x) for x in ROWS_BTM_2_TOP)

led_data_pin = Pin(22)
# configure wifi led pins for wifi user feedback
grn_wifi_led = Pin(10, Pin.OUT)
red_wifi_led = Pin(11, Pin.OUT)
brightness = 0.2
oled_fps = 5
oled_needs_check = True
oled_displayed_state = None  # ('image', style) or ('time', rtc[:6], style) or ('blank',)
display_phase = PHASE_IMAGE
wifi_check_pending = False
last_button_press = 0
dc = Pin(17)
rst = Pin(20)
cs = Pin(16)
mosi = Pin(19)
sck = Pin(18)
fullscreen_px_x = 128  # SSD1306 horizontal resolution
fullscreen_px_y = 64   # SSD1306 vertical resolution
digit_px_x = 24
digit_px_y = 32
colon_px_x = 16
date_start_x = 0
date_start_y = 0
digit_start_y = 16
tens_hr_digit_start_x = 4
ones_hr_digit_start_x = 32
colon_start_x = 56
tens_min_digit_start_x = 72
ones_min_digit_start_x = 100
mini_style_start_x = 0 
mini_style_start_y = 56
none_px_x = 8
none_px_y = 1

button = Pin(15, Pin.IN, Pin.PULL_UP)
onboard_led = Pin(25, Pin.OUT)

rtc = RTC()
sda = Pin(12)
scl = Pin(13)
i2c = I2C(0, sda=sda, scl=scl, freq=I2C_FREQ)
i2c_devices = i2c.scan()
print("I2C Devices: {}".format(i2c_devices))
eeprom = EEPROM_24LC512(i2c, i2c_devices[0])


def read_config_file(filename):
    json_data = None
    with open(filename) as fp:
        json_data = ujson.load(fp)
    return json_data


def wifi_led_red():
    grn_wifi_led.off()
    red_wifi_led.on()


def wifi_led_green():
    red_wifi_led.off()
    grn_wifi_led.on()


connection = ""
wifi_led_red()


def get_frame_buffer(img_ba, x_px, y_px):
    if img_ba is None:
        return framebuf.FrameBuffer(img_utils.get_time_img(None), none_px_x, none_px_y, framebuf.MONO_HLSB)
    else:
        return framebuf.FrameBuffer(img_ba, x_px, y_px, framebuf.MONO_HLSB)


def display_image(byte_array=None):
    if byte_array:
        # Load image into the framebuffer64)
        fb = get_frame_buffer(byte_array, fullscreen_px_x, fullscreen_px_y)
        # Clear oled display
        oled.fill(0)
        oled.blit(fb, 1, 1)
        oled.show()
    else:
        oled.fill(0)
        oled.show()


def init_esp8266():
    esp8266_at_ver = None
    print("StartUP", esp01.startUP())
    print("Echo-Off", esp01.echoING())
    print("\n")

    '''
    Print ESP8266 AT comand version and SDK details
    '''
    esp8266_at_ver = esp01.getVersion()
    if(esp8266_at_ver != None):
        print(esp8266_at_ver)

    '''
    set the current WiFi in SoftAP+STA
    '''
    esp01.setCurrentWiFiMode(WIFI_MODE)
    esp01.deviceHostname(config["wifi"]["hostname"])
    print(esp01.deviceHostname())
    # apList = esp01.getAvailableAPs()
    # for items in apList:
    #    print(items)


def connect_wifi():
    global oled_displayed_state
    display_image(img_utils.get_system_ba("wifi"))
    print("Attempting to connect to wifi AP!")
    ssid = bytes(config["wifi"]["ssid"], 'utf-8')
    password = bytes(config["wifi"]["password"], 'utf-8')
    connection_status = esp01.connectWiFi(
        base64.b64decode(ssid).decode("utf-8"),
        base64.b64decode(password).decode("utf-8")
    )
    if connection_status in ESP8266_WIFI_CONNECTED:
        print("Successfully connected to the wifi AP!")
    oled_displayed_state = None
    return connection_status


def get_wifi_conn_status(conn_status, bool_query_time):
    if conn_status and conn_status in ESP8266_WIFI_CONNECTED:
        wifi_led_green()
        if bool_query_time:
            conn_status = set_time()
        print("wifi connected --> {}".format(conn_status))
    else:
        wifi_led_red()
        print("sorry, cant connect to wifi AP! connection --> {}".format(conn_status))
    return conn_status


def set_time():
    global oled_displayed_state
    display_image(img_utils.get_system_ba("set_time"))
    query_time_api(config["time_api"]["ntp_server"], config["time_api"]["tz_offset"])
    oled_displayed_state = None
    status = get_wifi_conn_status(esp01.getWifiAccessPointConnectionStatus(), False)


SNTP_DOW_MAP = {
    "Mon": 0, "Tue": 1, "Wed": 2, "Thu": 3,
    "Fri": 4, "Sat": 5, "Sun": 6
}
SNTP_MONTH_MAP = {
    "Jan": 1, "Feb": 2, "Mar": 3, "Apr": 4,
    "May": 5, "Jun": 6, "Jul": 7, "Aug": 8,
    "Sep": 9, "Oct": 10, "Nov": 11, "Dec": 12
}


def set_rtc_from_sntp(time_str):
    # Format: "Thu May  8 14:30:00 2026" — split() handles multiple spaces
    parts = time_str.split()
    dow   = SNTP_DOW_MAP.get(parts[0], 0)
    month = SNTP_MONTH_MAP.get(parts[1], 1)
    day   = int(parts[2])
    h, m, s = (int(x) for x in parts[3].split(":"))
    year  = int(parts[4])
    rtc.datetime((year, month, day, dow, h, m, s, 0))
    print("RTC set from SNTP: {}".format(time_str))



def query_time_api(ntp_server, tz_offset):
    try:
        time_str = esp01.getSNTPTime(tz_offset=tz_offset, server=ntp_server)
        if time_str:
            set_rtc_from_sntp(time_str)
        else:
            print("SNTP returned no time; keeping previous RTC")
    except Exception as e:
        print("query_time_api failed; keeping previous RTC: {}".format(e))


def write_style_index_to_eeprom(index):
    eeprom.write(STYLE_ADDRESS, index.to_bytes(STYLE_BYTES, 'big'))
    print("Style index wrote to EEPROM: {}".format(index))


# create dict from config file
config = read_config_file(CONFIG_FILE)
# Create an SPI Object and use it for oled display
oled_timer = Timer()
spi = SPI(SPI_PORT, SPI_FREQ, mosi=mosi, sck=sck)
oled = SSD1306_SPI(fullscreen_px_x, fullscreen_px_y, spi, dc, rst, cs)
display_image(img_utils.get_system_ba("hello"))

# initialize LED string stuff
led_style_list = img_utils.get_style_list()
style_index = int.from_bytes(eeprom.read(STYLE_ADDRESS, STYLE_BYTES), 'big')
if style_index >= len(led_style_list):
    style_index = 0
    write_style_index_to_eeprom(style_index)
print("Style index from EEPROM: {}".format(style_index))
led_style = led_style_list[style_index]
led_string = Neopixel(led_data_pin, NUM_LEDS, brightness)
led_string.clear_pixels()
led_string.pixels_show()

# Wrap pixels_show so OLED state checks happen at a safe point — right after
# the WS2812 frame has been clocked out and latched.
_neopixel_show = led_string.pixels_show
def _pixels_show_with_oled():
    _neopixel_show()
    _process_oled()
    _process_wifi_check()
led_string.pixels_show = _pixels_show_with_oled

# Create an ESP8266 Object, init, and connect to wifi AP
wifi_timer = Timer()
esp01 = ESP8266(uart_port, UART_BAUD, uart_tx_pin, uart_rx_pin)
init_esp8266()
connection = get_wifi_conn_status(connect_wifi(), True)


def update_oled_display(oled_timer):
    # Hard IRQ context: just flag — actual SPI work runs from main loop.
    global oled_needs_check
    oled_needs_check = True


def _process_oled():
    # Called from main-loop context after each pixels_show, where it's safe
    # to do SPI without corrupting an in-flight WS2812 transmission.
    global oled_needs_check, oled_displayed_state, display_phase
    if not oled_needs_check:
        return
    oled_needs_check = False
    elapsed = time() - last_button_press
    if elapsed < INACTIVITY_TIMER:
        display_phase = PHASE_IMAGE
        target = ('image', led_style)
        if oled_displayed_state != target:
            display_image(img_utils.get_style_img(led_style))
            oled_displayed_state = target
    elif elapsed < BLANK_TIMER:
        display_phase = PHASE_TIME
        # Cache by year/month/day/weekday/hour/minute + style — only redraw
        # when one of those changes (typically once a minute).
        target = ('time', tuple(rtc.datetime()[:6]), led_style)
        if oled_displayed_state != target:
            display_date_and_time()
            oled_displayed_state = target
    else:
        display_phase = PHASE_BLANK
        if oled_displayed_state != ('blank',):
            display_image()
            oled_displayed_state = ('blank',)


def update_conn_status(wifi_timer):
    # Hard IRQ context: just flag — UART AT commands, HTTP, and SPI display
    # writes are too heavy to do here, and any exception in IRQ would leave
    # the SPI/UART peripherals in an unknown state.
    global wifi_check_pending
    wifi_check_pending = True


def _process_wifi_check():
    # Called from main-loop context after each pixels_show. Same SPI bus as
    # _process_oled, so doing this here (instead of from the timer IRQ)
    # avoids preempting an in-flight OLED transfer.
    global wifi_check_pending, connection
    if not wifi_check_pending:
        return
    wifi_check_pending = False
    try:
        if esp01.getWifiAccessPointConnectionStatus() not in ESP8266_WIFI_CONNECTED:
            connection = get_wifi_conn_status(connect_wifi(), True)
        else:
            set_time()
    except Exception as e:
        print("wifi check failed: {}".format(e))


def button_press_isr(irq):
    global last_button_press, onboard_led, oled_needs_check
    last_button_press = time()
    onboard_led.on()
    if display_phase == PHASE_IMAGE:
        go_to_next_style()
    oled_needs_check = True
    onboard_led.off()


def go_to_next_style():
    global led_style
    next_index = led_style_list.index(led_style) + 1
    if len(led_style_list) <= next_index:
        next_index = 0
    led_style = led_style_list[next_index]
    write_style_index_to_eeprom(next_index)
    show_current_style(led_style)


def show_current_style(style):
    print("item {}: {}".format(led_style_list.index(style)+1, style))


def do_rainbow_cycle(wait=20):
    for j in range(255):
        for i in range(NUM_LEDS):
            rc_index = int(i * 255 / NUM_LEDS) + j
            led_string.pixels_set(i, Neopixel.wheel(rc_index & 255))
        led_string.pixels_show()
        if not led_style == "rainbow":
            break
        sleep_ms(wait)


def color_chase(color, wait):
    for i in range(NUM_LEDS):
        led_string.pixels_set(i, color)
        sleep_ms(wait)
        led_string.pixels_show()
        if not led_style == "chase":
            break
    sleep_ms(20)


def vertical_color_chase(color, wait, dir, rows):
    chase_direction = ''.join([dir, "-cha"])
    for i in range(NUM_ROWS):
        [led_string.pixels_set(led-1, color) for led in rows[i]]
        sleep_ms(wait)
        led_string.pixels_show()
        if not led_style == chase_direction:
            return
    sleep_ms(20)


def do_rainbow_ttb(wait=10):
    # rows need to be traversed in opposite dir of rainbow
    vertical_rainbow(wait, "ttb", ROWS_BTM_2_TOP)


def do_rainbow_btt(wait=10):
    # rows need to be traversed in opposite dir of rainbow
    vertical_rainbow(wait, "btt", ROWS_TOP_2_BTM)


def vertical_rainbow(wait, dir, rows):
    bow_direction = ''.join([dir, "-bow"])
    for j in range(255):
        for i in range(NUM_ROWS):
            rc_index = int(i * 255 / NUM_ROWS) + j
            [led_string.pixels_set(led-1, Neopixel.wheel(rc_index & 255)) for led in rows[i]]
        led_string.pixels_show()
        if not led_style == bow_direction:
            break
        sleep_ms(wait)


def do_chase():
    for color in led_string.get_colors():
        color_chase(color, 10)
        if not led_style == "chase":
            return


def do_chase_ttb():
    vertical_chase("ttb", ROWS_TOP_2_BTM)


def do_chase_btt():
    vertical_chase("btt", ROWS_BTM_2_TOP)


def vertical_chase(dir, rows, wait=45):
    chase_direction = ''.join([dir, "-cha"])
    for color in led_string.get_colors():
        vertical_color_chase(color, wait, dir, rows)
        if not led_style == chase_direction:
            return


def do_chasebow():
    for j in range(255):
        mask = j % 2
        for i in range(NUM_LEDS):
            rc_index = int(i * 255 / NUM_LEDS) + j*16
            color = Neopixel.wheel(rc_index & 255)
            led_string.pixels_set(i, (color[0]*mask, color[1]*mask, color[2]*mask))
            sleep_ms(20)
            led_string.pixels_show()
            if not led_style == "chasebow":
                return
        sleep_ms(10)


def solid_color(color, style_compare_str):
    led_string.pixels_fill(color)
    led_string.pixels_show()
    for t in range(10):
        if not led_style == style_compare_str:
            return 1
        sleep_ms(100)


def do_fill():
    for color in led_string.COLORS:
        returned_val = solid_color(color, "fill")
        if returned_val == 1:
            return


def do_off():
    solid_color(led_string.BLACK, "off")


def do_red():
    solid_color(led_string.RED, "red")


def do_yellow():
    solid_color(led_string.YELLOW, "yellow")


def do_green():
    solid_color(led_string.GREEN, "green")


def do_cyan():
    solid_color(led_string.CYAN, "cyan")


def do_blue():
    solid_color(led_string.BLUE, "blue")


def do_purple():
    solid_color(led_string.PURPLE, "purple")


def do_white():
    solid_color(led_string.WHITE, "white")


def do_firefly():
    colors = led_string.get_firefly_colors()
    max_len = 20
    min_len = 5
    #pixelnum, posn in flash, flash_len, direction
    flashing = []
    num_flashes = 10
    for i in range(num_flashes):
        pix = random.randint(0, NUM_LEDS - 1)
        col = random.randint(1, len(colors) - 1)
        flash_len = random.randint(min_len, max_len)
        flashing.append([pix, colors[col], flash_len, 0, 1])

    led_string.clear_pixels()
    while True:
        led_string.pixels_show()
        for i in range(num_flashes):
            pix = flashing[i][0]
            brightness = (flashing[i][3]/flashing[i][2])
            color = (int(flashing[i][1][0]*brightness),
                    int(flashing[i][1][1]*brightness),
                    int(flashing[i][1][2]*brightness))
            led_string.pixels_set(pix, color)
            if flashing[i][2] == flashing[i][3]:
                flashing[i][4] = -1
            if flashing[i][3] == 0 and flashing[i][4] == -1:
                pix = random.randint(0, NUM_LEDS - 1)
                col = random.randint(0, len(colors) - 1)
                flash_len = random.randint(min_len, max_len)
                flashing[i] = [pix, colors[col], flash_len, 0, 1]
            flashing[i][3] = flashing[i][3] + flashing[i][4]
            if not led_style == "firefly":
                return
            sleep_ms(5)


def do_blend():
    hue = 0
    while(True):
        color = Neopixel.colorHSV(hue, 255, 150)
        led_string.pixels_fill(color)
        led_string.pixels_show()
        sleep_ms(20)
        hue += 150
        if not led_style == "blend":
            return


def do_flash():
    led_string.pixels_fill((10, 10, 10))
    led_string.pixels_show()
    while True:
        for i in range(NUM_LEDS):
            for j in range(NUM_LEDS):
                led_string.pixels_set(j,\
                    (abs(i+j) % 10, abs(i-(j+3)) % 10, abs(i-(j+6)) % 10))
            led_string.pixels_show()
            sleep_ms(50)
            if not led_style == "flash":
                return


def do_comet():
    trail_len = 8
    pos = 0
    while True:
        led_string.clear_pixels()
        for i in range(trail_len + 1):
            p = (pos - i) % NUM_LEDS
            v = GAMMA[max(0, 255 - i * 32)]
            led_string.pixels_set(p, (v, v, v))
        led_string.pixels_show()
        pos = (pos + 1) % NUM_LEDS
        if not led_style == "comet":
            return
        sleep_ms(40)


def do_fireball():
    # pixels_set takes (G, R, B) — confirmed from neopixel.py constants
    # 1px white head → yellow → orange (bulk) → red → dim red tail
    COLORS = [
        (255, 255, 200),  # 0 head: white hot
        (230, 255,  50),  # 1 white-yellow
        (200, 255,   0),  # 2 yellow
        (150, 255,   0),  # 3 yellow-orange
        ( 90, 240,   0),  # 4 orange
        ( 50, 210,   0),  # 5 deep orange
        ( 20, 170,   0),  # 6 orange-red
        (  0, 120,   0),  # 7 red
        (  0,  40,   0),  # 8 tail: dying ember
    ]
    trail_len = 8
    pos = 0
    while True:
        led_string.clear_pixels()
        for i in range(trail_len + 1):
            p = (pos - i) % NUM_LEDS
            g, r, b = COLORS[i]
            led_string.pixels_set(p, (GAMMA[g], GAMMA[r], GAMMA[b]))
        led_string.pixels_show()
        pos = (pos + 1) % NUM_LEDS
        if not led_style == "fireball":
            return
        sleep_ms(40)


def do_aurora():
    # Slow drift through greens, cyans, blues, purples — gamma-corrected so
    # the dim end of the curve is perceptually smooth instead of stepping.
    t = 0.0
    while True:
        for i in range(NUM_LEDS):
            h = int(sin(t * 0.7 + i * 0.22) * 14000 + 35000) & 0xFFFF
            color = Neopixel.colorHSV(h, 230, 200)
            led_string.pixels_set(i, (GAMMA[color[0]], GAMMA[color[1]], GAMMA[color[2]]))
        led_string.pixels_show()
        t += 0.08
        if not led_style == "aurora":
            return
        sleep_ms(50)


def do_ember():
    # Warm-tone sibling to aurora — drifts through greens, yellows, oranges.
    # Hue range ~5000..21000 (16-bit) covers red-orange through yellow to green.
    t = 0.0
    while True:
        for i in range(NUM_LEDS):
            h = int(sin(t * 0.7 + i * 0.22) * 8000 + 13000) & 0xFFFF
            color = Neopixel.colorHSV(h, 230, 200)
            led_string.pixels_set(i, (GAMMA[color[0]], GAMMA[color[1]], GAMMA[color[2]]))
        led_string.pixels_show()
        t += 0.08
        if not led_style == "ember":
            return
        sleep_ms(50)


def do_vortex():
    # Razer Vortex-inspired ambient swirl: rainbow bands rotate through
    # the tree. Brightness held flat — depth comes from a wider hue
    # spread across rows and radial distance, plus a saturation shimmer.
    t = 0.0
    while True:
        phase = int(t * 3800)
        for row_index in range(NUM_ROWS):
            row = ROWS_BTM_2_TOP[row_index]
            center = (len(row) - 1) / 2
            for slot_index in range(len(row)):
                led = row[slot_index]
                distance = abs(slot_index - center) / (center + 1)
                wave = sin(t * 1.3 + row_index * 0.7 + slot_index * 1.1)
                h = int(phase + row_index * 8200 + distance * 21000 + wave * 5200) & 0xFFFF
                s = 205 + int((wave + 1.0) * 25)
                color = Neopixel.colorHSV(h, s, 200)
                led_string.pixels_set(led - 1, (GAMMA[color[0]], GAMMA[color[1]], GAMMA[color[2]]))
        led_string.pixels_show()
        t += 0.07
        if not led_style == "vortex":
            return
        sleep_ms(22)


def do_solstice():
    # Warm amber lower, cool aqua upper, with a hue ripple that climbs
    # through the rows. Brightness held flat — depth comes from richer
    # per-pixel hue swings and a saturation shimmer riding on top.
    t = 0.0
    while True:
        breath = (sin(t * 0.55) + 1.0) / 2.0
        ripple_phase = t * 1.8
        for row_index in range(NUM_ROWS):
            row = ROWS_BTM_2_TOP[row_index]
            row_mix = row_index / (NUM_ROWS - 1)
            base_hue = int(7500 + row_mix * 34500)
            ripple = sin(ripple_phase - row_index * 0.7)
            for slot_index in range(len(row)):
                led = row[slot_index]
                shimmer = sin(t * 1.4 + row_index * 0.8 + slot_index * 1.4)
                h = int(base_hue + shimmer * 4400 + breath * 2400 + ripple * 3000) & 0xFFFF
                s = 200 + int((shimmer + 1.0) * 25)
                color = Neopixel.colorHSV(h, s, 180)
                led_string.pixels_set(led - 1, (GAMMA[color[0]], GAMMA[color[1]], GAMMA[color[2]]))
        led_string.pixels_show()
        t += 0.06
        if not led_style == "solstice":
            return
        sleep_ms(28)


def get_date_string(now):
    year = str(now[0])
    month = img_utils.get_month(now[1])
    day = now[2]
    day_of_wk = img_utils.get_day_of_week(now[3])
    return ''.join([day_of_wk, ', ', "{0}{1:2}".format(month, day), ', ', year])


def get_time_tuple(now):
    hours = now[4]
    minutes = now[5]
    return (int(hours / 10), hours % 10, int(minutes / 10), minutes % 10)


def display_date_and_time():
    current_time = rtc.datetime()
    # Clear oled display
    oled.fill(0)
    create_date_text(get_date_string(current_time))
    create_time_image(get_time_tuple(current_time))
    create_style_text(led_style)
    oled.show()
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

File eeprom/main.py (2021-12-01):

from machine import I2C, Pin
from EEPROM_24LC512 import EEPROM_24LC512

INT_BYTES = 4

sda = Pin(12)
scl = Pin(13)
i2c = I2C(0, sda=sda, scl=scl, freq=1000000)
i2c_devices = i2c.scan()
print("I2C Devices: ")
print(i2c_devices)

eeprom = EEPROM_24LC512(i2c, i2c_devices[0])

style_address = 0
style_index = 1
eeprom.write(style_address, style_index)
stored_style_index = eeprom.read(style_address, INT_BYTES)
print(stored_style_index)

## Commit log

2021-11-29 thread the rgb string
2021-11-29 get button press toggling led
2021-11-30 change num leds to 33 from 50 update readme
2021-12-03 print messages when things happen
2021-12-03 modify httpParse so that it parses correctly it was leaving a ' on the end of the json
    [main.py]
2021-12-03 modify readme add led wifi indication grn -> connected red -> not connected
2021-12-04 slow down blend mode fix glitchy lighting on rainbow cycle (cast as int)
    [main.py]
2021-12-04 remove unused imports refactor some code test chainging rainbow cycle loop to 255 rather than 256
2021-12-04 use the correct default pins for the esp other minor tweaks for bug fix / troubleshooting
    [esp8266.py, main.py]
2021-12-04 dont cipclose b/c i get resets on the wifi ap
    [esp8266.py]
2021-12-05 trying to work around esp01 issues losing conn
    [main.py]
2021-12-05 fix readme (it got messed up with version control add kicad files
2021-12-05 add the files i said i added last commit
    [raspi_pico_christmas_tree.kicad_pcb, raspi_pico_christmas_tree.sch]
2021-12-05 remove global vars and replace with config params create a conf directory use a config.json to store information read from the file on start up and store info in json obj dict
    [main.py]
2021-12-06 fix readme rem todo items that cant be done rem todo itsems that are done reconnect to wifi once a day and set time
    [main.py]
2021-12-06 fix a wrong var name
    [main.py]
2021-12-06 fix a problem with the date overflowing display
    [main.py]
2021-12-07 add a bunch of pcb files mark pcb off todo list
    [raspi_pico_christmas_tree-B_Cu.gbr, raspi_pico_christmas_tree-B_Mask.gbr, raspi_pico_christmas_tree-B_Paste.gbr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]
2022-01-02 kicad files
2022-01-03 add hostname function change hostname to led-tree
2025-11-07 use 6_400_000 for the neopixel freq as its more stable. removes glitchy visual issues
    [neopixel.py]
2026-05-03 add instructions for uploading a single file to the Pico using mpremote
2026-05-03 update time API host and path for accurate time retrieval; adjust SPI frequency for stability
    [main.py]
2026-05-03 Add new LED effects: comet, aurora, and ember
    - Introduced three new lighting effects for LED display:
    - `do_comet()`: Creates a trailing comet effect with a smooth transition.
    - `do_aurora()`: Generates a slow drifting aurora effect with gamma correction.
    - `do_ember()`: Produces a warm-tone ember effect transitioning through greens, yellows, and oranges.
    - Added gamma correction for smoother brightness transitions.
    - Updated the style function list to include the new effects.
    - Added corresponding image assets for the new effects.
    [main.py]
2026-05-03 Add vortex and solstice LED effects with corresponding images
2026-05-03 Implement robust error handling for time API queries and add wifi check processing
    [main.py]
2026-05-03 Enhance vortex and solstice LED effects with improved brightness modulation and depth perception
2026-05-08 Add fireball LED effect with corresponding image and update style dictionary
2026-05-08 Switch time sync from HTTP API to ESP8266 SNTP
2026-05-08 Add three-phase OLED timeout: effect image → time → blank with wake-before-advance button
2026-05-09 fix: invalidate oled_displayed_state after wifi and time-sync screen writes to prevent display getting stuck
    [main.py]

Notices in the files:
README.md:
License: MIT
